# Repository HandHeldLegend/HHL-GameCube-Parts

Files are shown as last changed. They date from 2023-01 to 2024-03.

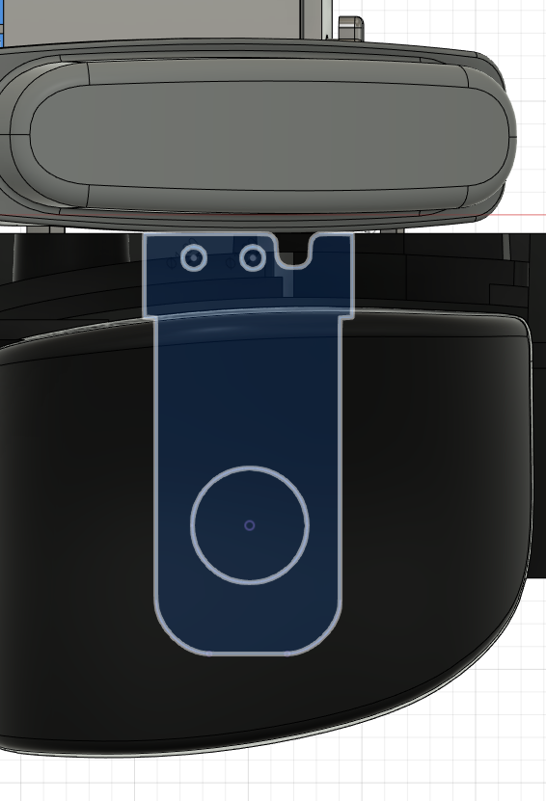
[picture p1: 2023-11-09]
PCB/Drawings/TriggerPCB Orientation.png

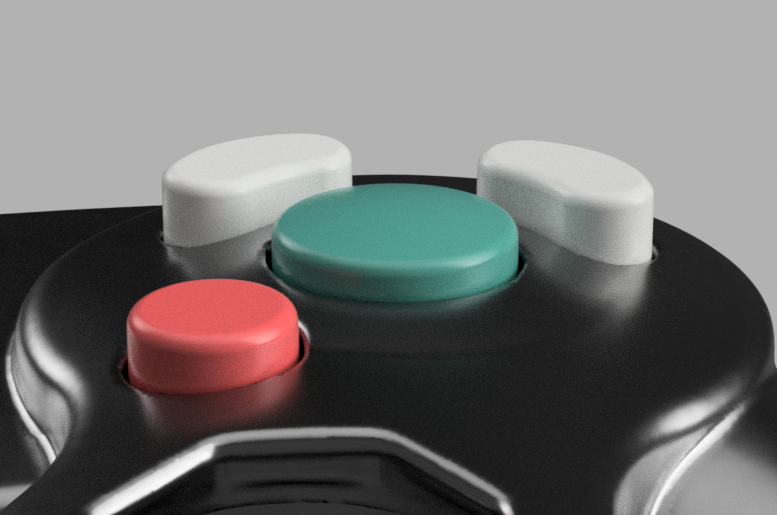
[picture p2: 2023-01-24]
Buttons/Buttons Render.png

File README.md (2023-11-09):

# HHL-GameCube-Parts

3D Printable GameCube controller parts.

Do whatever you want with the files according to the license. 
Keep these parts open and available for anyone to use.

Mold them, print them, sell them, we don't care. Just provide attribution and retain the same license for derivatives.

## Attributions
Ergo trigger profiles modelled after work from [Mikey](https://twitter.com/yaboimikey97) with permission provided.

Controller shell is, in large part, modelled using great reference scans provided by [Wesk on BitBuilt](https://bitbuilt.net/forums/index.php?threads/gamecube-oem-controller-scan.3844/).

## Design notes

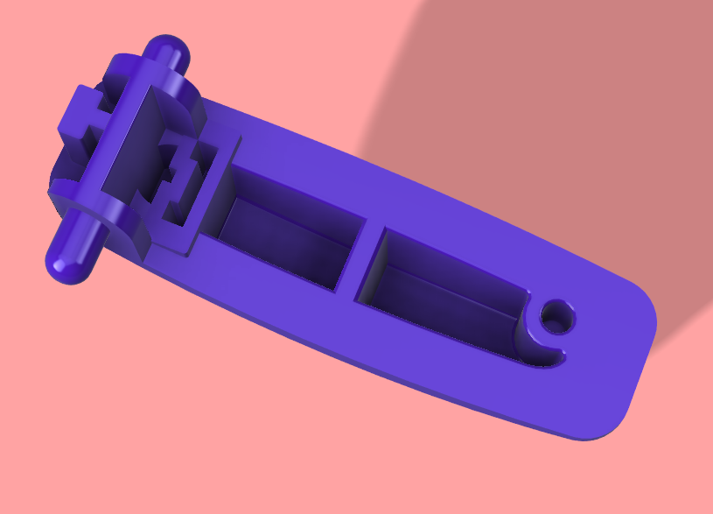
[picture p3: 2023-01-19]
Z Button/Z Bottom.png

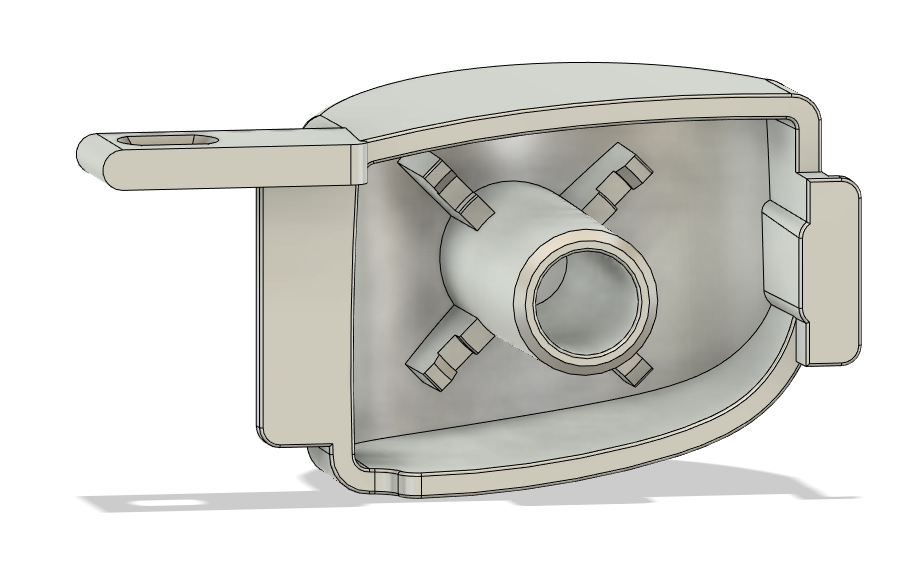
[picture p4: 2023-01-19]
Triggers/Rear View Hollow.png

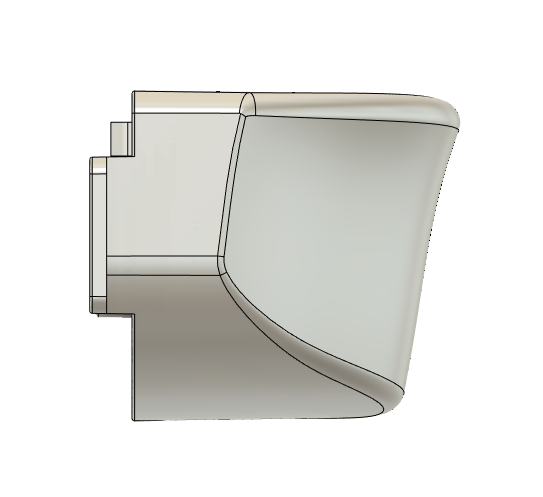
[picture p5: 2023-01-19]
Triggers/Side Profile.png

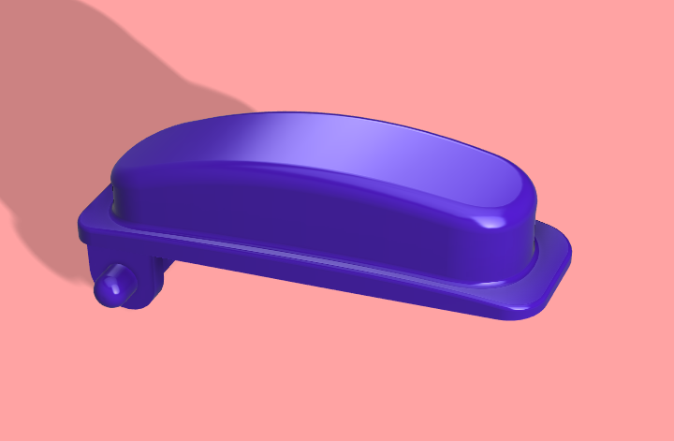
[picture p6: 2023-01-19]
Z Button/Z Top.png

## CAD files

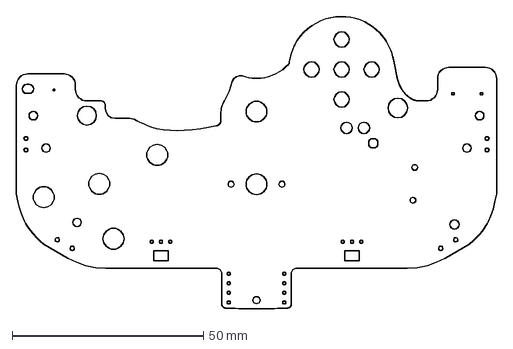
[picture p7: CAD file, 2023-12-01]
PCB/Drawings/UGC_Main.dxf
125.7 x 76.5 mm

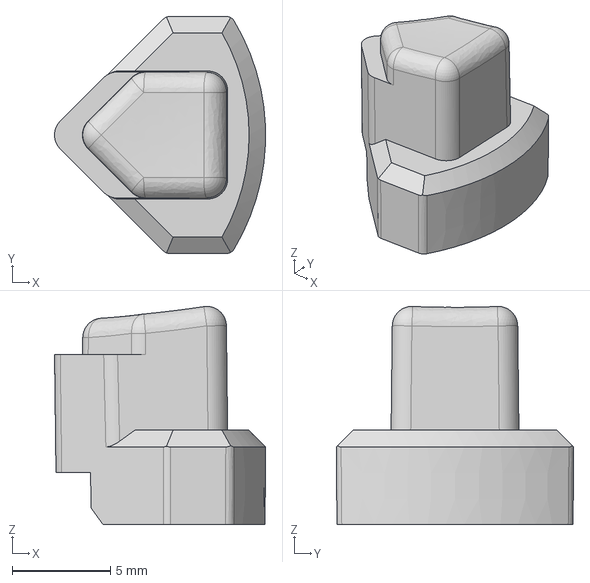
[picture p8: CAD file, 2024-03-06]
Buttons/D-Pad Split Button.step
10.7 x 12.1 x 11.1 mm

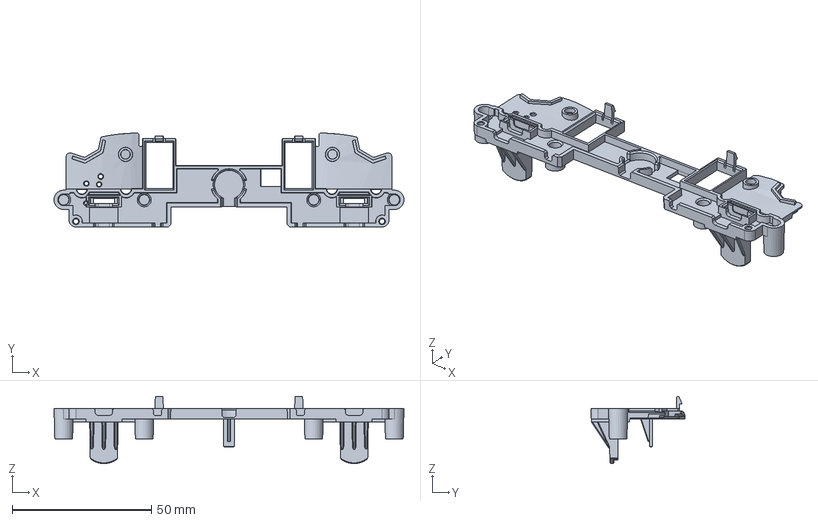
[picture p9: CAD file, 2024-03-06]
GC Ultimate/Trigger Bracket.step
125.9 x 33.8 x 24.2 mm

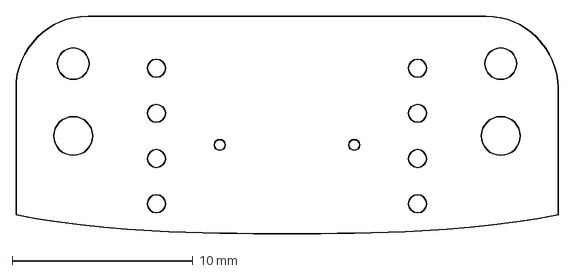
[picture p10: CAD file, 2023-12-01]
PCB/Drawings/UGC_USB.dxf
30.0 x 12.0 mm

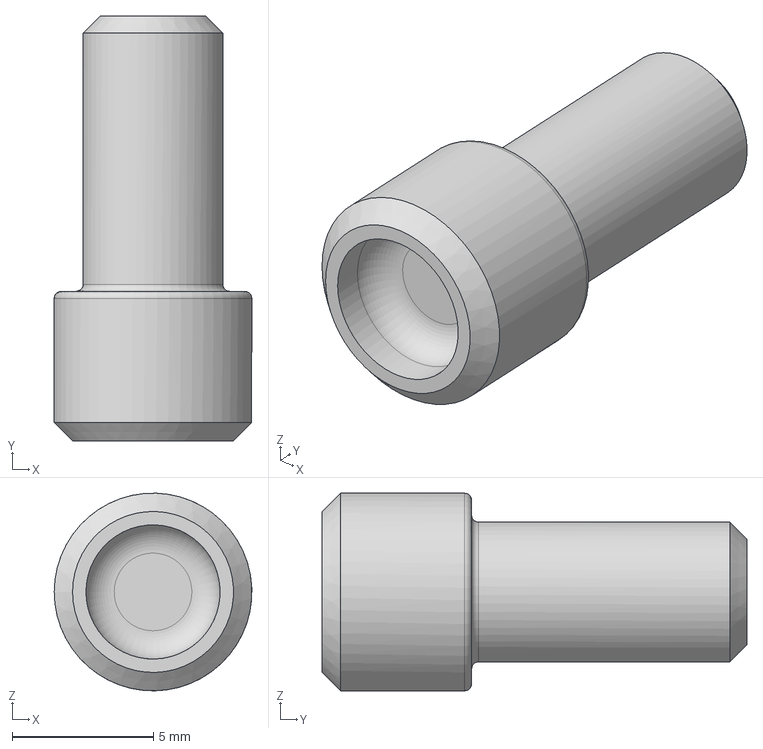
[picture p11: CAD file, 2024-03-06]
Trigger Plugs/Long Trigger Plug.step
7.00 x 15.1 x 7.00 mm

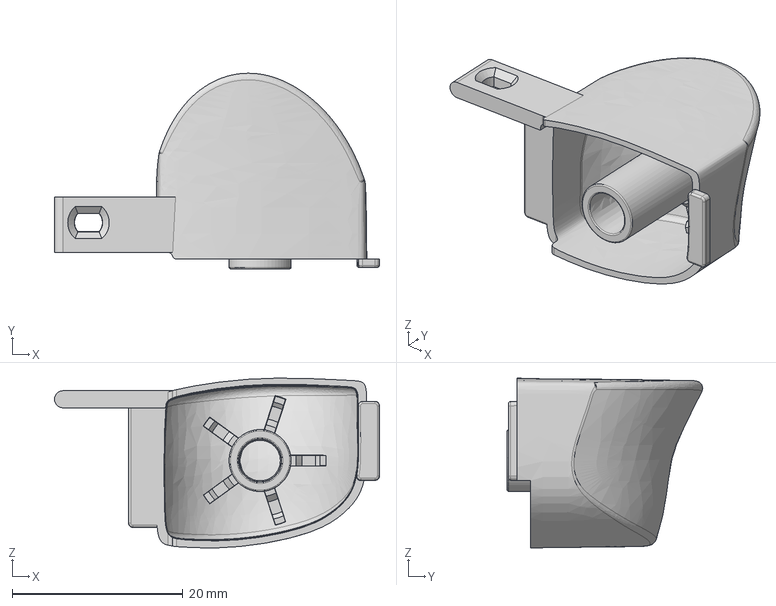
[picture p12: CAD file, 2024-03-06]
Triggers/HHL Ergo Trigger R.step
38.0 x 22.9 x 19.9 mm

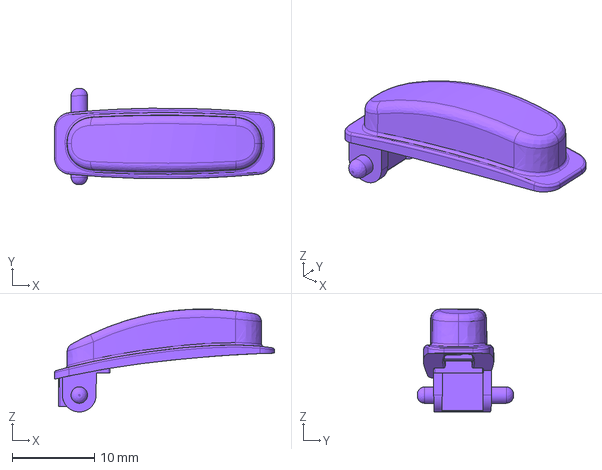
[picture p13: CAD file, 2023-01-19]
Z Button/HHL Z Button.step
26.8 x 11.7 x 12.5 mm

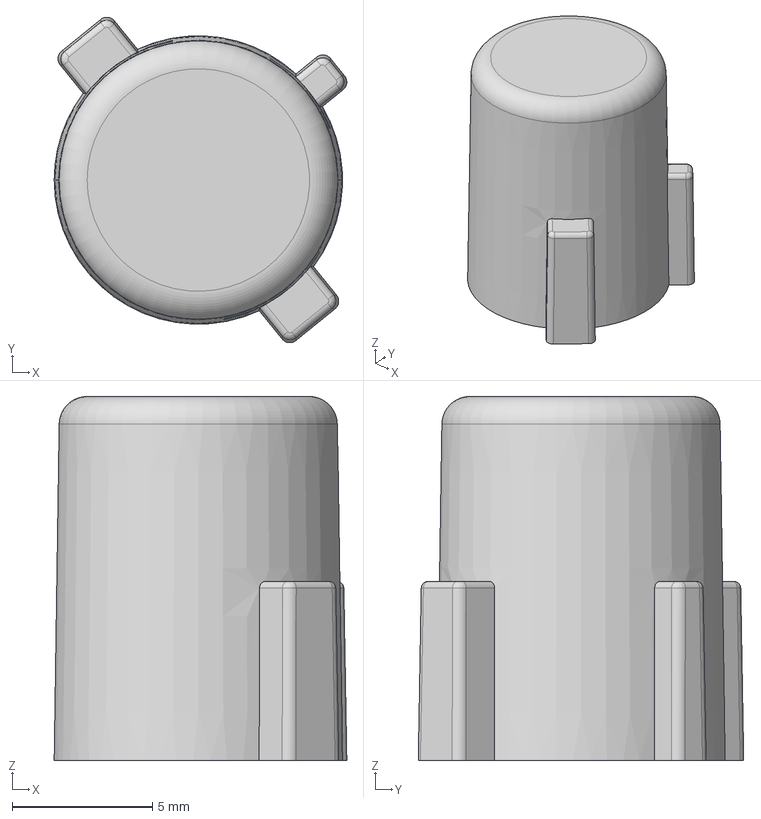
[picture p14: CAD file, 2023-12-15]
Buttons/B Button.step
10.5 x 11.6 x 13.0 mm

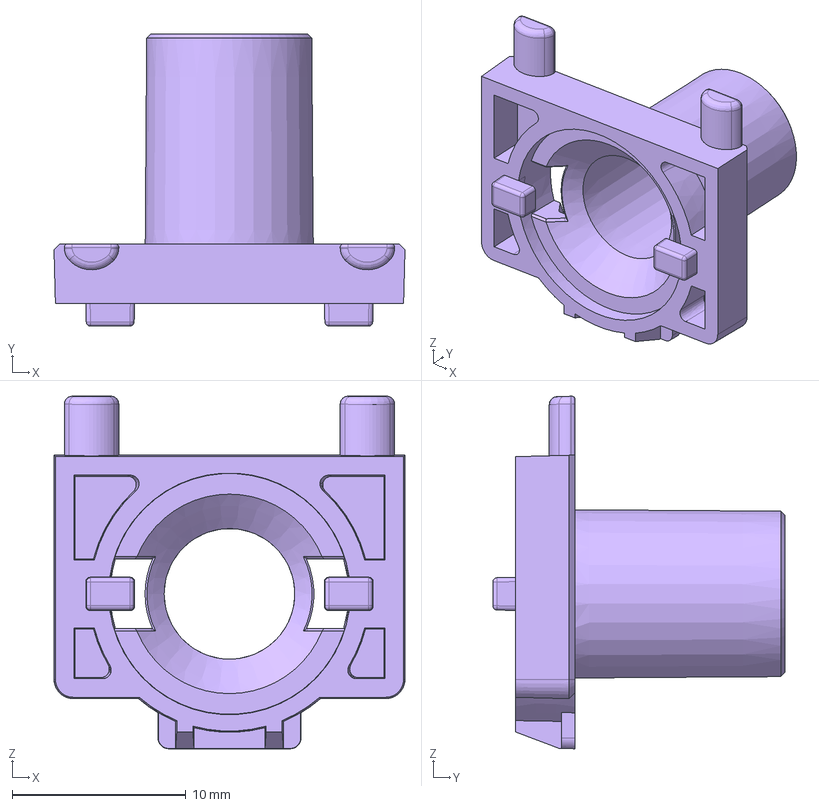
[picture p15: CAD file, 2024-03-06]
GC Ultimate/MembraneTriggerHolder.step
20.2 x 16.9 x 20.3 mm

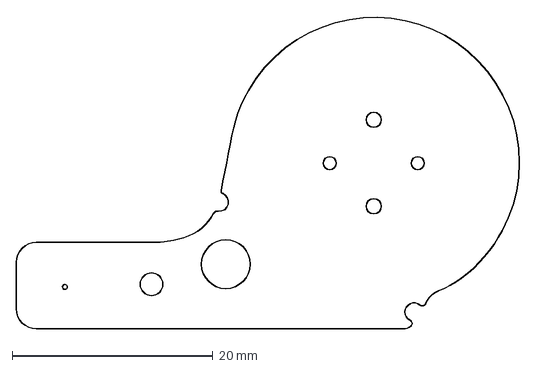
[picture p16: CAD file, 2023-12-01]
PCB/Drawings/UGC_Stick.dxf
50.2 x 31.2 mm

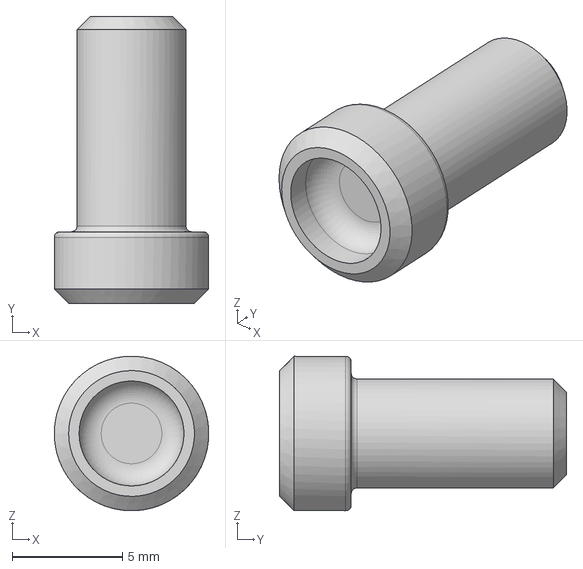
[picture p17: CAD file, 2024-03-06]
Trigger Plugs/Short Trigger Plug.step
7.00 x 13.0 x 7.00 mm

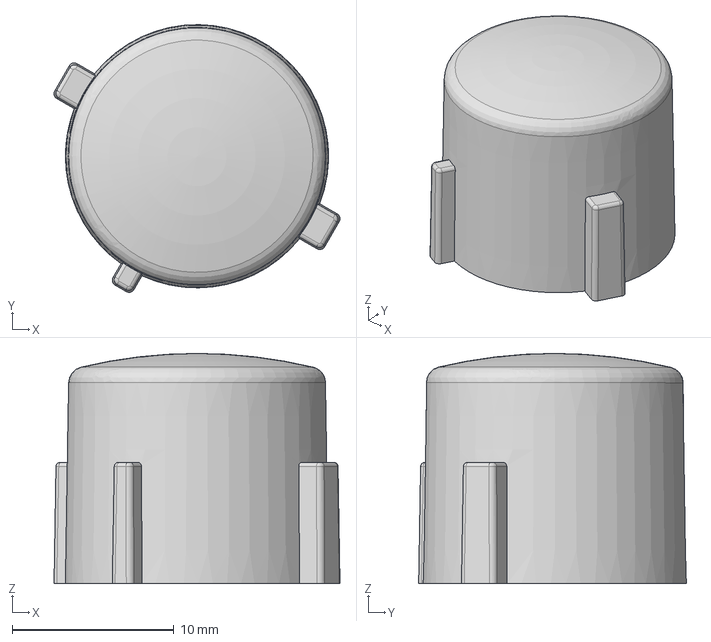
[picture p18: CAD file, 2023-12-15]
Buttons/A Button.step
17.7 x 16.6 x 14.2 mm

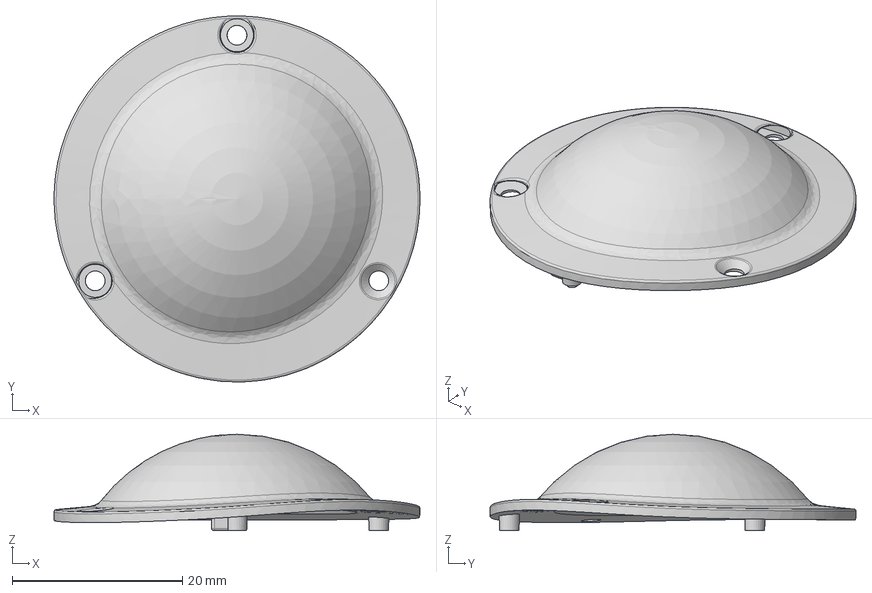
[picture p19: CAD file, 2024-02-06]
GC Ultimate/GatePlate Blank.step
43.0 x 43.0 x 11.8 mm

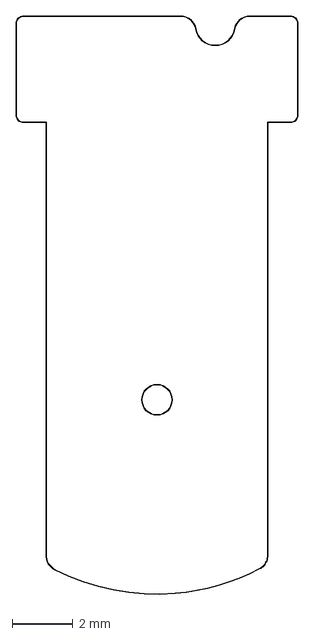
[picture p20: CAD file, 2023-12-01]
PCB/Drawings/UGC_Trigger.dxf
9.30 x 19.1 mm

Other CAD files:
Triggers/STL/TriggerErgoL.stl
Triggers/HHL Ergo Trigger L.step
Triggers/STL/TriggerErgoR.stl
Z Button/HHL Z Button Mirrored.step
Buttons/D-Pad Button.step
Buttons/Start Button.step
Buttons/X Button.step
Buttons/Y Button.step
GC Ultimate/GatePlate Octagon.step
GC Ultimate/GatePlate Round.step
GC Ultimate/STL/GatePlateOctagon.stl
GC Ultimate/STL/GatePlateRound.stl
GC Ultimate/STL/MembraneTriggerHolder.stl
GC Ultimate/STL/TriggerBracket.stl

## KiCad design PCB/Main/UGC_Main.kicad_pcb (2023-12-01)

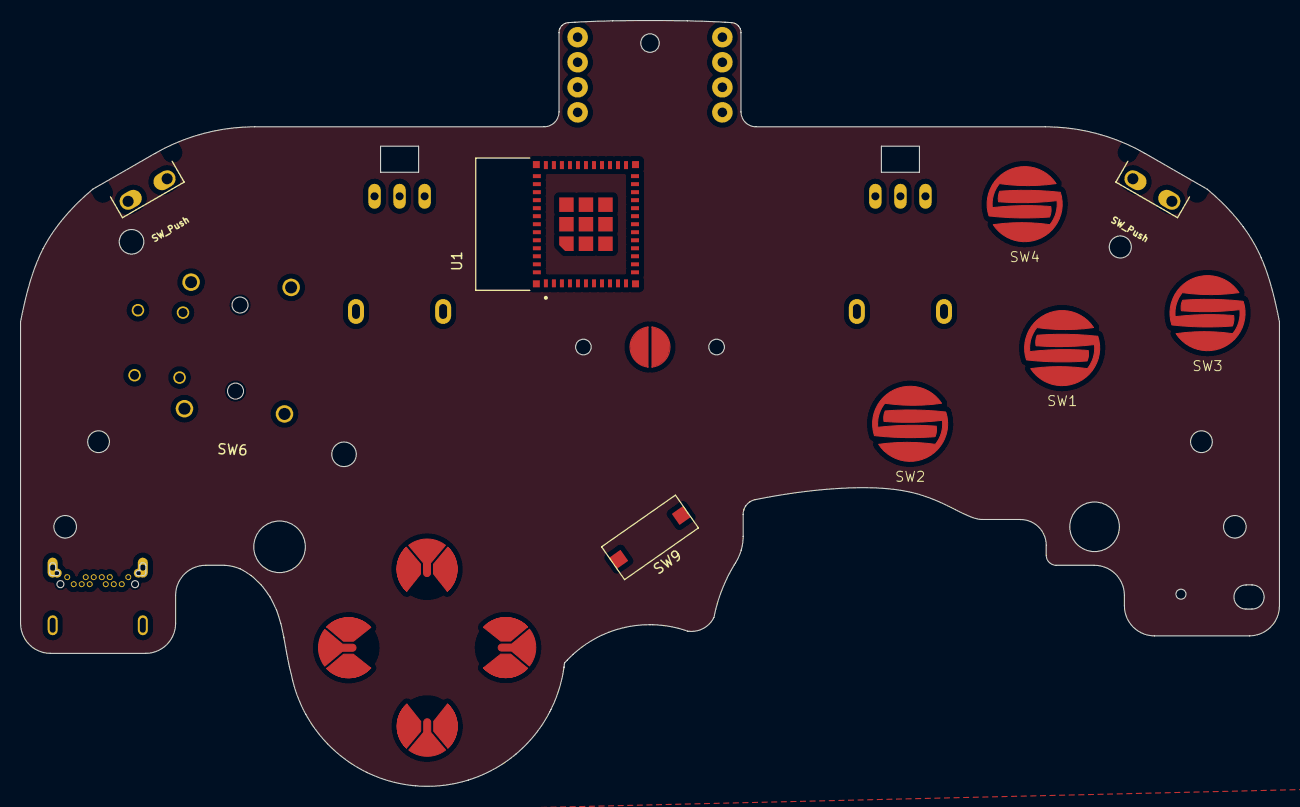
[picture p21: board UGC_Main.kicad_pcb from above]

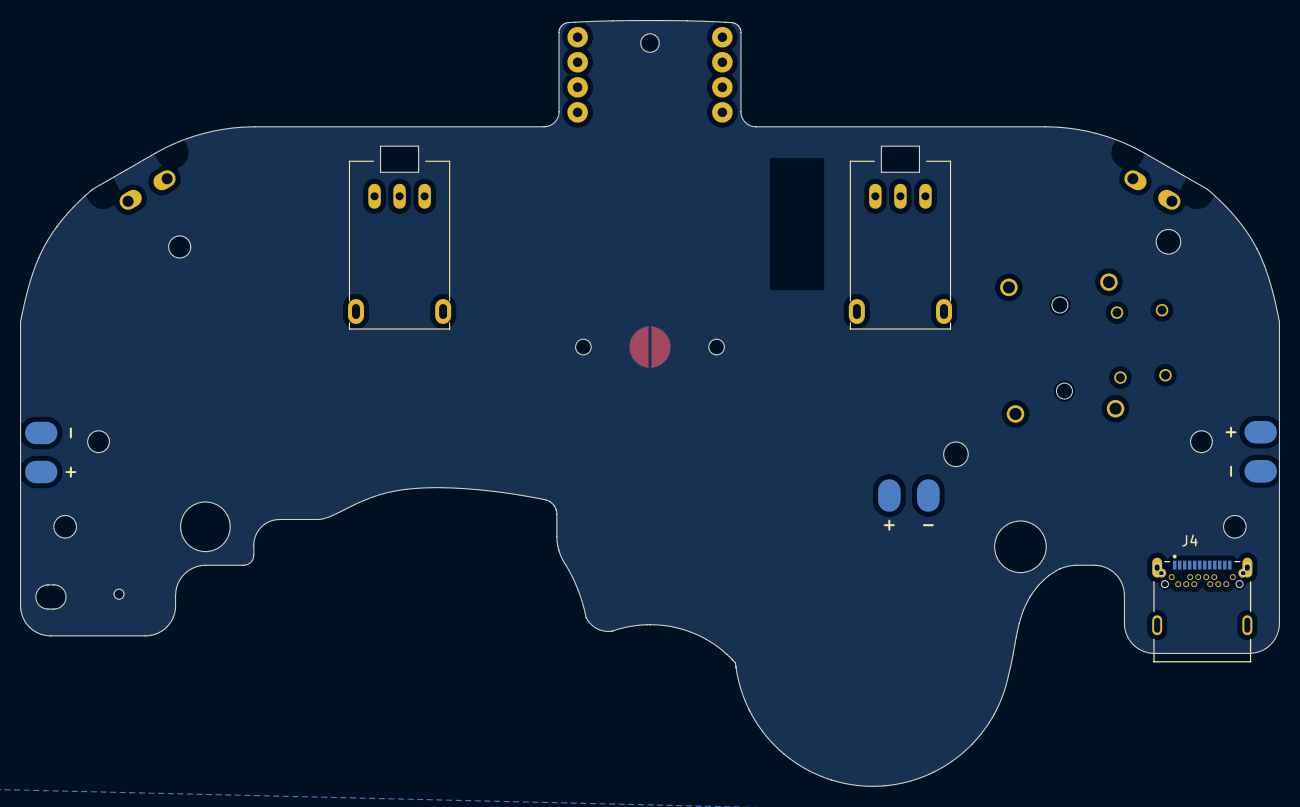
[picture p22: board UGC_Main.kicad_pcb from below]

Board: 2 copper layers, 125.7 x 76.4 mm, 28 parts (6 on the bottom side), 4 nets, no tracks yet.

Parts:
J1: Rumble; rumble_pins
J2: LT; rumble_pins
J3: RT; rumble_pins
J4: UJ31-CH-G1-SMT-TR; CUI_UJ31-CH-G1-SMT-TR
J5, J6, J7, J8, J9, J10, J11, J12: Conn_01x01_Pin; YZ72015053P-01
RV1, RV2: Slider_GCC-Gamecube_MB; GCC_Slider
SW1, SW2, SW3, SW4: SW_Push; progcc_bpad
SW5: SW_Push; snes_pad
SW6: GL18_SW; GL18
SW7, SW8: SW_Push; Z_Switch_Edge_Omron
SW9: TS09-63-25-R-260-SMT; TS09
SW10, SW11, SW12, SW13: SW_Push; progcc_dpad
U1: ESP32-PICO-MINI-02; MODULE_ESP32-PICO-MINI-02

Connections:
unnamed: J4.A1 (GND), J4.A12 (GND), J4.B1 (GND), J4.B12 (GND)
unnamed: J4.SH1 (SHIELD), J4.SH2 (SHIELD), J4.SH3 (SHIELD), J4.SH4 (SHIELD), J4.SH5 (SHIELD), J4.SH6 (SHIELD)
unnamed: J4.A4 (VBUS), J4.A9 (VBUS), J4.B4 (VBUS), J4.B9 (VBUS)
unnamed: U1.1 (GND), U1.2 (GND), U1.11 (GND), U1.14 (GND), U1.36 (GND), U1.37 (GND), U1.38 (GND), U1.39 (GND), U1.40 (GND), U1.41 (GND), U1.42 (GND), U1.43 (GND), U1.44 (GND), U1.45 (GND), U1.46 (GND), U1.47 (GND), U1.48 (GND), U1.49 (GND), U1.50 (GND), U1.51 (GND), U1.52 (GND), U1.53 (GND), U1.54 (GND), U1.55 (GND), U1.56 (GND), U1.57 (GND), U1.58 (GND), U1.59 (GND), U1.60 (GND), U1.61 (GND)

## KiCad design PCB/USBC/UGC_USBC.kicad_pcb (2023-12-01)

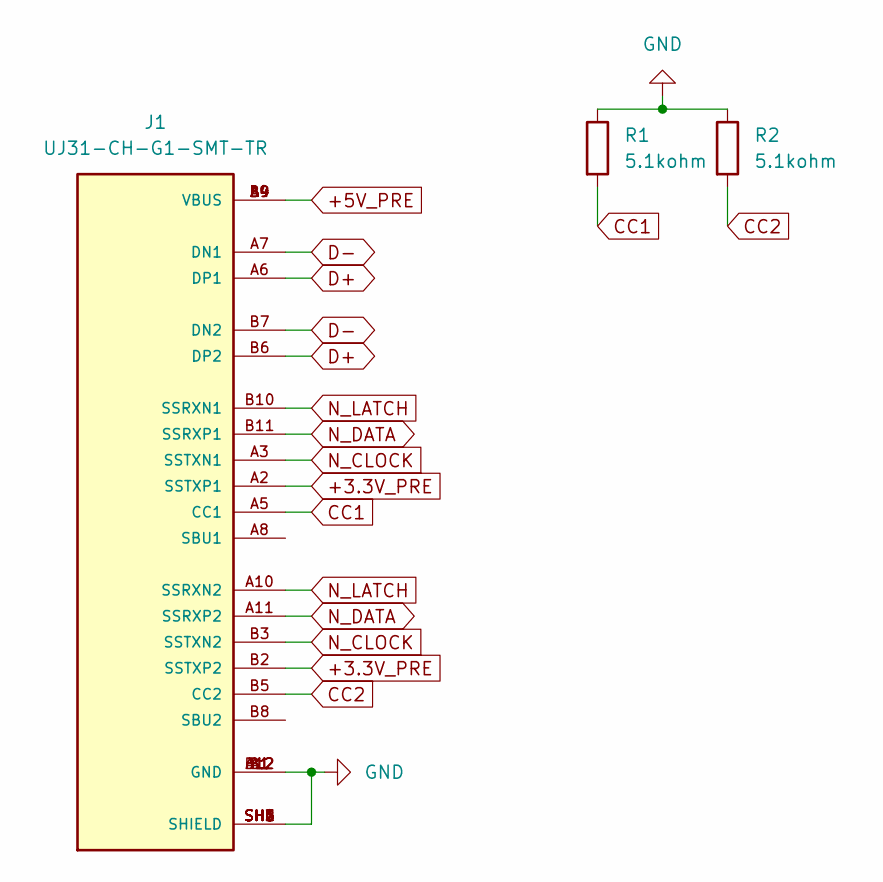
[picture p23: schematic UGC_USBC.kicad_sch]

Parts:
J1: UJ31-CH-G1-SMT-TR; CUI_UJ31-CH-G1-SMT-TR; PART_REV 1.01
R1, R2: 5.1kohm; R_0603_1608Metric

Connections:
+3.3V_PRE: J1.A2 (SSTXP1), J1.B2 (SSTXP2)
+5V_PRE: J1.A4 (VBUS), J1.A9 (VBUS), J1.B4 (VBUS), J1.B9 (VBUS)
CC1: J1.A5 (CC1), R1.2
CC2: J1.B5 (CC2), R2.2
D+: J1.A6 (DP1), J1.B6 (DP2)
D-: J1.A7 (DN1), J1.B7 (DN2)
GND: J1.A1 (GND), J1.A12 (GND), J1.B1 (GND), J1.B12 (GND), J1.SH1 (SHIELD), J1.SH2 (SHIELD), J1.SH3 (SHIELD), J1.SH4 (SHIELD), J1.SH5 (SHIELD), J1.SH6 (SHIELD), R1.1, R2.1
N_CLOCK: J1.A3 (SSTXN1), J1.B3 (SSTXN2)
N_DATA: J1.A11 (SSRXP2), J1.B11 (SSRXP1)
N_LATCH: J1.A10 (SSRXN2), J1.B10 (SSRXN1)

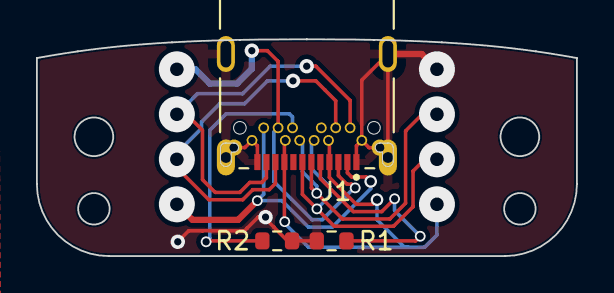
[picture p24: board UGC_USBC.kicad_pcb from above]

Board: 2 copper layers, 30.0 x 12.0 mm, 3 parts (0 on the bottom side), 10 nets.

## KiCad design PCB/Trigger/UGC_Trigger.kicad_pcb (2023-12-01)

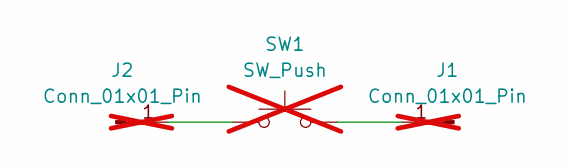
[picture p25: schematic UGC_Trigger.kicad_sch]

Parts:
J1, J2: Conn_01x01_Pin; PinHeader_1x01_P2.00mm_Vertical; not fitted
SW1: SW_Push; snes_pad; not fitted

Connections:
unnamed: J1.1, SW1.2
unnamed: J2.1, SW1.1

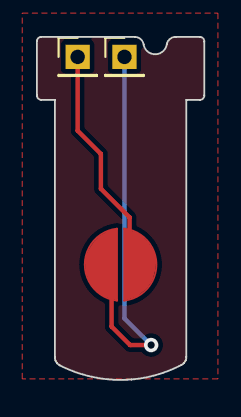
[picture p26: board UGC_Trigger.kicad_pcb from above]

Board: 2 copper layers, 9.3 x 19.1 mm, 3 parts (0 on the bottom side), 2 nets.

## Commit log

2023-01-19 Add Z Button
    [HHL Z Button Mirrored.step, HHL Z Button.step]
2023-01-19 Update trigger size
    slightly larger (0.3%)
    [HHL Ergo Trigger L.step, HHL Ergo Trigger R.step]
2023-01-20 Add A button
    [HHL A Baldie.step, HHL A OEM.step]
2023-01-20 Add B button
    [HHL B Baldie.step, HHL B OEM.step]
2023-01-24 Remove balds for now, redo OEM
    buttons are more accurate than ever with external dimensions.
    [A Button.step, B Button.step, HHL A Baldie.step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]
2023-01-25 Added d-pad and start buttons.
    [D-Pad Button.step, Start Button.step]
2023-01-30 Removed faulty ergo filled trigger, add new trigger
    [HHL Ergo Trigger L.step, HHL Ergo Trigger Printable L.step, HHL Ergo Trigger Printable R.step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]
2023-01-30 Adjust stem taper dimension
    [HHL Ergo Trigger L.step, HHL Ergo Trigger R.step]
2023-02-25 Adjusted ergo triggers and Dpad
    Fixed an issue with ergo triggers where they wouldn't click. The stem needed to be extended by 1.3mm to actuate the button
    [D-Pad Button.step, HHL Ergo Trigger L.step, HHL Ergo Trigger R.step]
2023-02-25 One final trigger update
    Increase depth inside to match OEM
    [HHL Ergo Trigger L.step, HHL Ergo Trigger R.step]
2023-03-12 Increase width of spring wells
    [HHL Ergo Trigger L.step, HHL Ergo Trigger R.step]
2023-04-09 Updated stem inner/outer dimensions
    [HHL Ergo Trigger L.step, HHL Ergo Trigger R.step]
2023-06-28 Resolve bad stitching on A button
    [A Button.step]
2023-11-09 GC Shell Update
    [GatePlate.step, MembraneTriggerHolder.step, Trigger Bracket.step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]
2023-11-09 Update pcb lib
2023-12-01 Update shell and PCB
    [GatePlate Octagon.step, GatePlate Round.step, GatePlate.step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]
2023-12-02 Restitch
    Restitch files and add STL shell
2023-12-14 Update
    - Increase face button thickness 0.25mm
    - Increase diameter of press-fit threaded inserts
    - Add battery wire cutout
    - Add battery connector cutout for trigger bracket
    [A Button.step, B Button.step, D-Pad Button.step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]
2023-12-15 Increase button top thickness
    0.25mm -> 0.5mm
    [A Button.step, B Button.step, Start Button.step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]
2023-12-22 Add updated plasticity files
    [Trigger Bracket.step]
2024-02-06 Update shell and gateplates
    - Add blank gate plate
    - Remove feature for USB-C sub-board (inconsistent connections)
    [GatePlate Blank.step]
2024-02-07 Few more changes
    - Adjust lower shell to have better trigger stops
    - Adjust trigger bracket for trigger stops
    - Adjust height on analog stick interfacing posts
    [MembraneTriggerHolder.step, Trigger Bracket.step]
2024-02-07 Few more changes
    - Update trigger membrane holder to allow proper trigger press distance
    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
    [MembraneTriggerHolder.step, Trigger Bracket.step]
2024-02-07 Add more stl
    gate plate stls
    [GatePlateOctagon.stl, GatePlateRound.stl]
2024-03-02 Add new variations
    - Introduce triggers with a slider mechanism (Will probably be gone soon, did not work well)
    - Split Dpad design (Untested)
    [D-Pad Split Button.step, Trigger Bracket Sliders.stl, Trigger W Sliders Left.stl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]
2024-03-06 Update and restructure
    [D-Pad Split Button.step, GatePlate Blank.step, GatePlate Octagon.step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]
2024-03-12 Update screw hole sizes and insert hole size
